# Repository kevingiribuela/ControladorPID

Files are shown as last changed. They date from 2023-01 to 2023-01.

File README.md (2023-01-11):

# ControladorPID
 Controlador PID desarrollado en 4to año de la carrera

## Descripción
Este diseño se realizó basandose en los principios del control robusto. El objetivo es realizar el control automático de una planta conocida pero cuyos parámetros pueden variar en función de agentes externos como lo son la temperatura, la humedad, etc. Es por eso que el controlador debe no solo controlar a la planta nominal sino que también a la familia de plantas involucradas en el modelo. 

La planta se trata de una serie de filtros pasabajos en cascada implementados con amplificadores operacionales, resistencias y capacitores. Los archivos correspondientes al diseño de la placa se encuentran en la presente documentación.

La placa es capaz de realizar una identificación de la planta a partir de un escalón a su entrada y enviar los datos en tiempo real a MATLAB para su procesamiento de datos y posterior modelado a partir de un modelo de primer orden. 



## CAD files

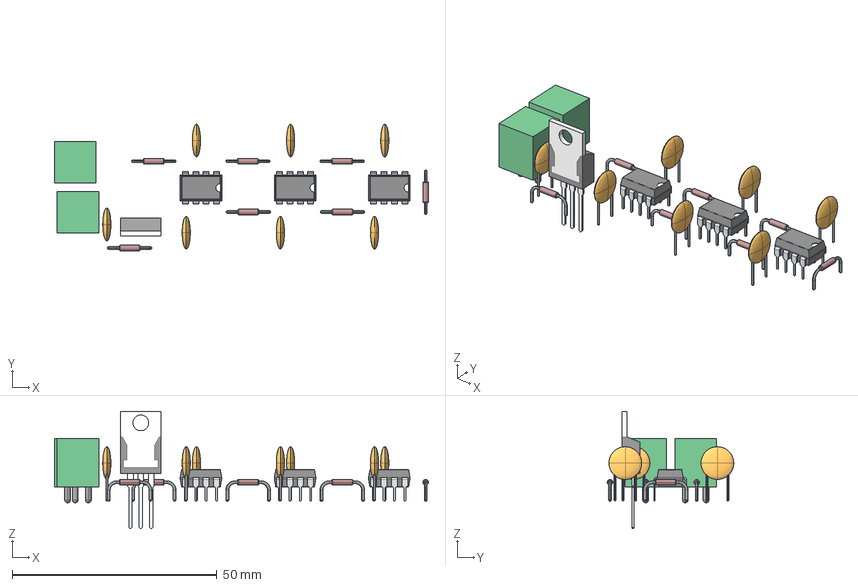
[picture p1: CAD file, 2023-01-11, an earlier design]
PCB/PCB_V1/Placa_control.STEP
91.4 x 30.9 x 28.6 mm
Pin_1 x 16
Pin_2 x 16

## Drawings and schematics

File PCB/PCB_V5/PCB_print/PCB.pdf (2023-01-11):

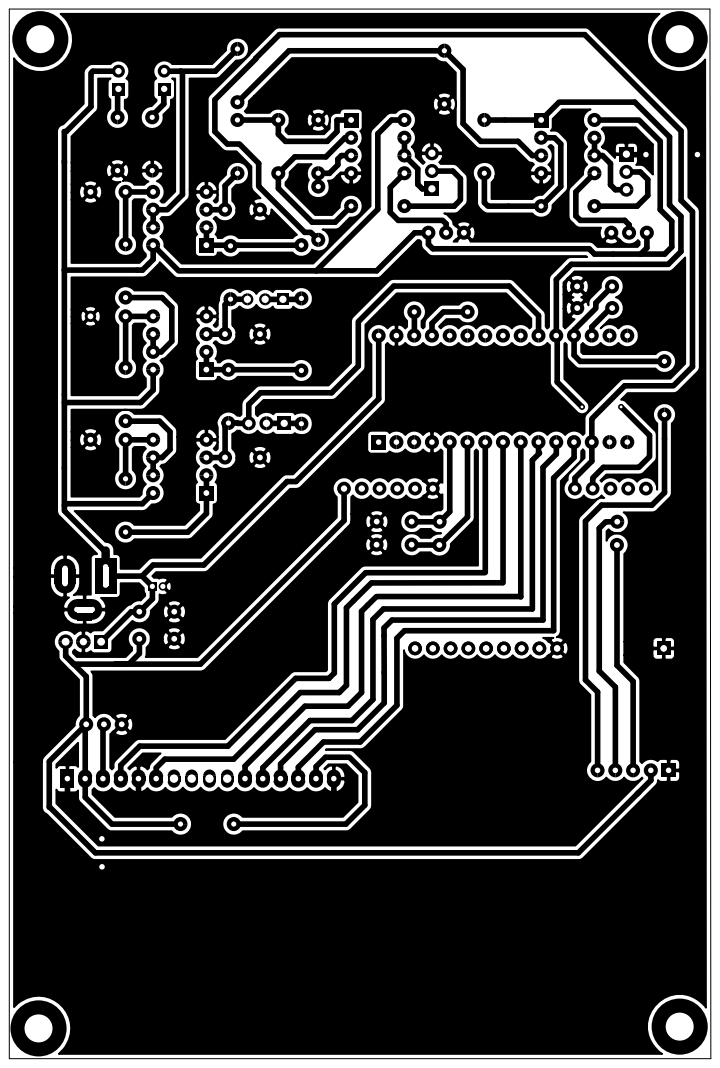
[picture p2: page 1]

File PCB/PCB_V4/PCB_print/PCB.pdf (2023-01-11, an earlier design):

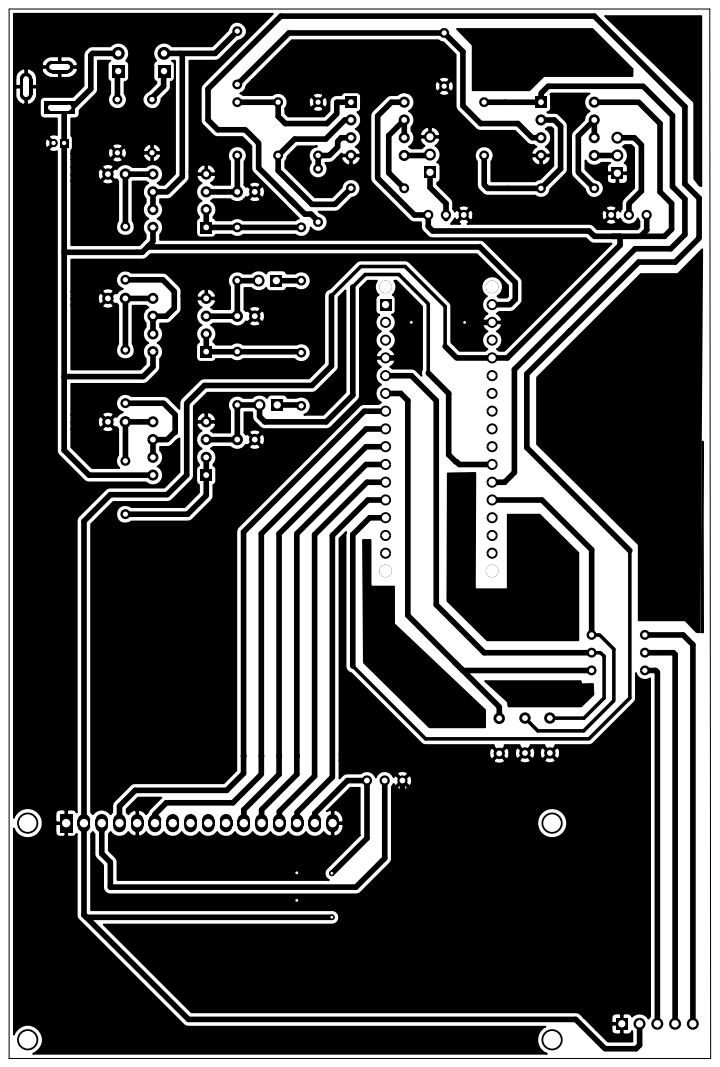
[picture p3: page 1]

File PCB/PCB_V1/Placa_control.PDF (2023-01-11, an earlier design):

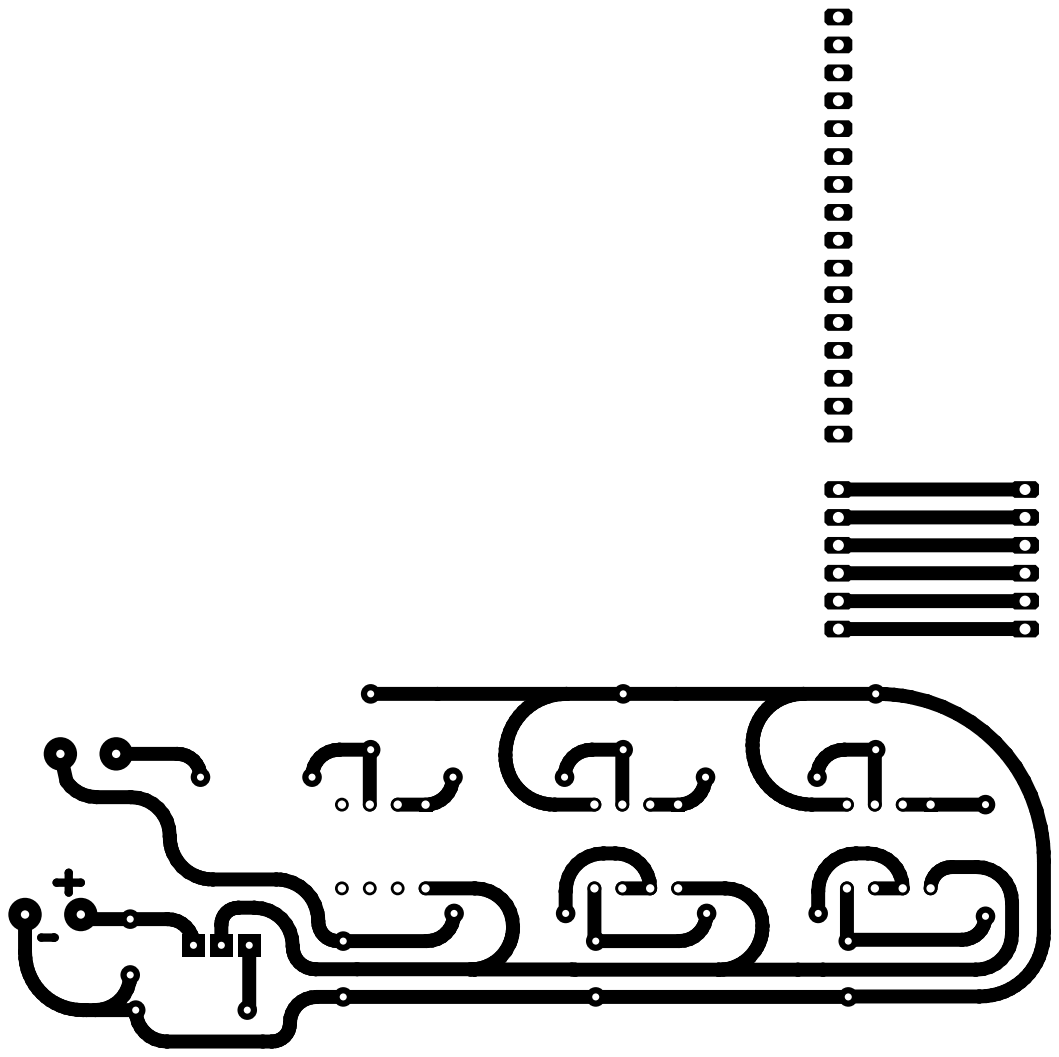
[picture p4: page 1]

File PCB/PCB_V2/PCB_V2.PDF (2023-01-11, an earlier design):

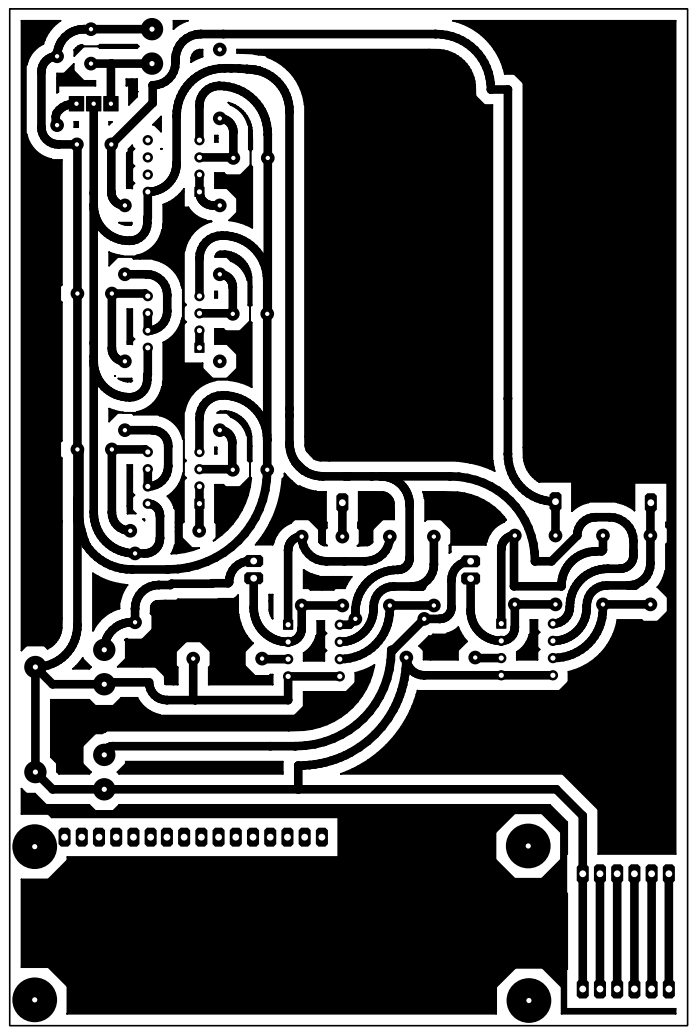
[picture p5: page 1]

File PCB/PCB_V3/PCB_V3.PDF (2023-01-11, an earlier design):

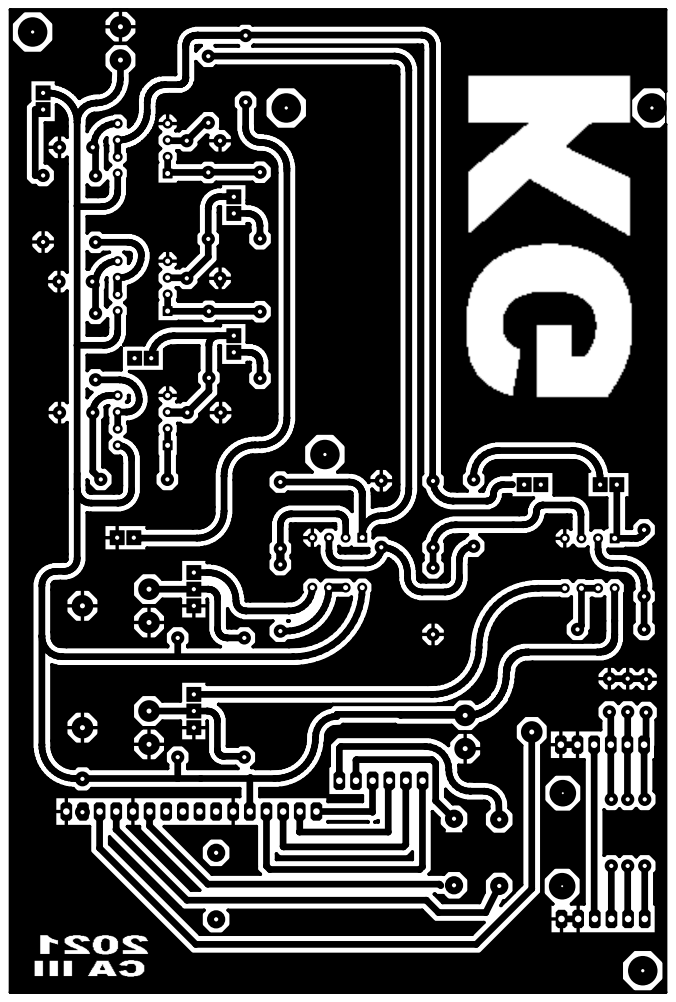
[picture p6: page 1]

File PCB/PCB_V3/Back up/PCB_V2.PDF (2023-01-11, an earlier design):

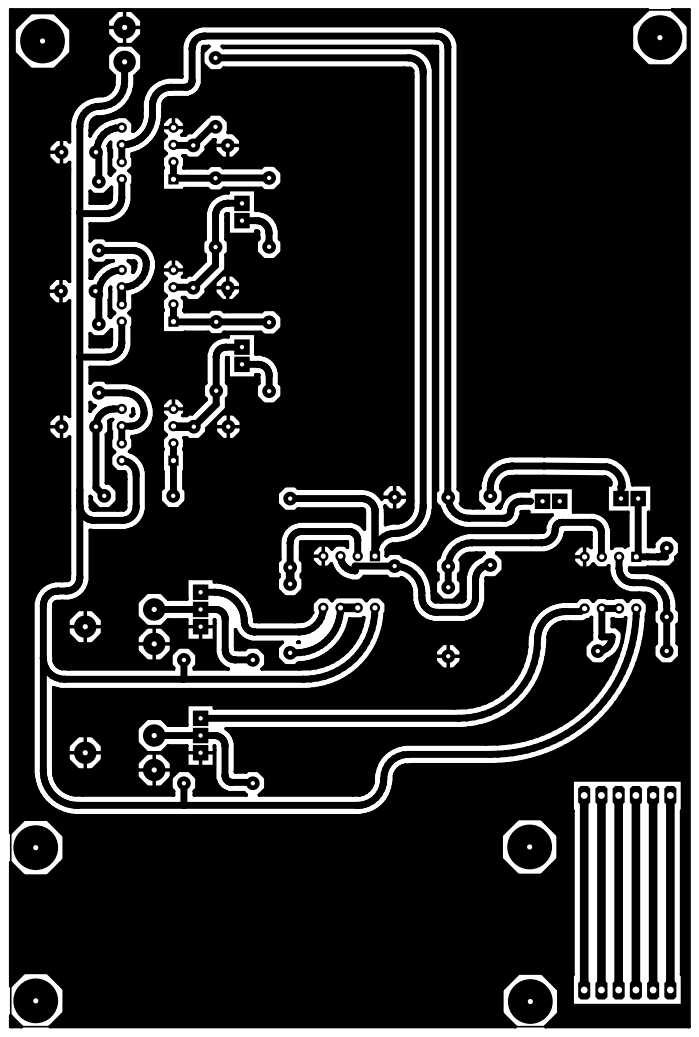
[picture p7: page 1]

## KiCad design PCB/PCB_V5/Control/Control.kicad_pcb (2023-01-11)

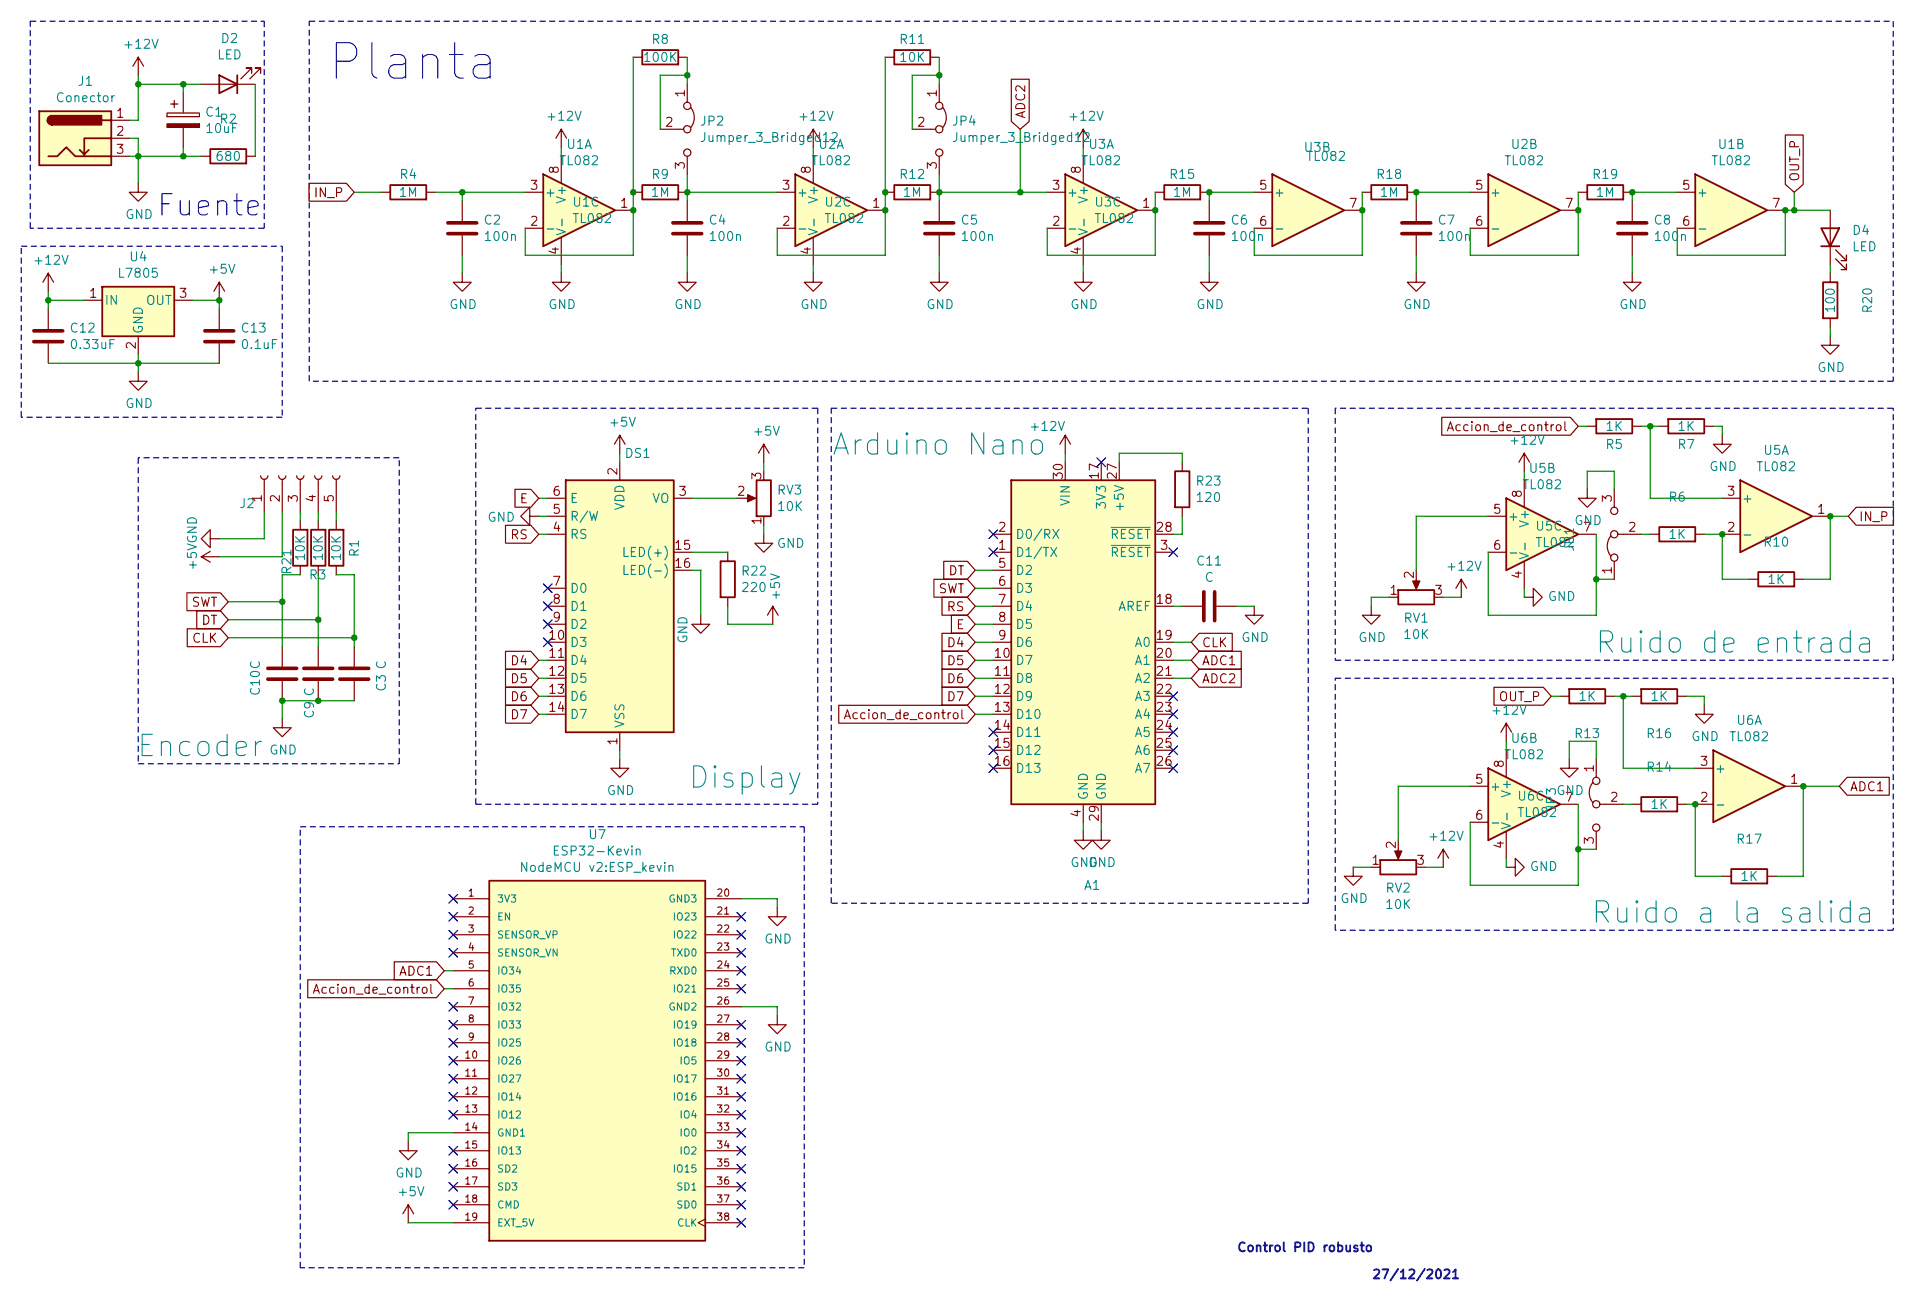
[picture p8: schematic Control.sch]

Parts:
A1: Arduino Nano; Arduino_Nano_WithMountingHoles
C1: 10uF; CP_Radial_D4.0mm_P1.50mm
C2, C4, C5, C6, C7, C8: 100n; C_Disc_D4.3mm_W1.9mm_P5.00mm
C3, C9, C10, C11: C; C_Disc_D4.3mm_W1.9mm_P5.00mm
C12: 0.33uF; C_Disc_D4.3mm_W1.9mm_P5.00mm
C13: 0.1uF; C_Disc_D4.3mm_W1.9mm_P5.00mm
D2, D4: LED; LED_D5.0mm_Clear
DS1: Display; WC1602A
J1: Conector; BarrelJack_Wuerth_6941xx301002
J2: Encoder; PinHeader_1x05_P2.54mm_Vertical
JP1: Ruido de entrada; PinHeader_1x03_P2.54mm_Vertical
JP2, JP4: Jumper_3_Bridged12; PinHeader_1x03_P2.54mm_Vertical
JP3: Ruido a la salida; PinHeader_1x03_P2.54mm_Vertical
R1, R11: 10K; R_Axial_DIN0204_L3.6mm_D1.6mm_P7.62mm_Horizontal
R2: 680; R_Axial_DIN0204_L3.6mm_D1.6mm_P7.62mm_Horizontal
R3, R21: 10K; R_Axial_DIN0309_L9.0mm_D3.2mm_P25.40mm_Horizontal
R4, R9, R12, R15, R18, R19: 1M; R_Axial_DIN0204_L3.6mm_D1.6mm_P7.62mm_Horizontal
R5, R6, R7, R10, R13, R14, R16, R17: 1K; R_Axial_DIN0204_L3.6mm_D1.6mm_P7.62mm_Horizontal
R8: 100K; R_Axial_DIN0204_L3.6mm_D1.6mm_P7.62mm_Horizontal
R20: 100; R_Axial_DIN0204_L3.6mm_D1.6mm_P7.62mm_Horizontal
R22: 220; R_Axial_DIN0204_L3.6mm_D1.6mm_P7.62mm_Horizontal
R23: 120; R_Axial_DIN0204_L3.6mm_D1.6mm_P7.62mm_Horizontal
RV1, RV2, RV3: 10K; Potentiometer_Bourns_3266Y_Vertical
U1, U2, U3: TL082; DIP-8_W7.62mm_Socket
U4: L7805; TO-220-3_Vertical
U5, U6: TL082; DIP-8_W7.62mm
U7: ESP32-Kevin; ESP_kevin; PARTREV 4

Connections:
+5V: C13.1, DS1.2 (VDD), J2.2, R22.2, RV3.3, U4.3 (OUT), U7.19 (EXT_5V)
+12V: A1.30 (VIN), C1.1, C12.1, D2.2 (A), J1.1, RV1.3, RV2.3, U1.8 (V+), U2.8 (V+), U3.8 (V+), U4.1 (IN), U5.8 (V+), U6.8 (V+)
ADC1: A1.20 (A1), R17.2, U6.1, U7.5 (IO34)
ADC2: A1.21 (A2), C5.1, JP4.3 (B), R12.2, U3.3 (+)
Accion_de_control: A1.13 (D10), R5.2, U7.6 (IO35)
CLK: A1.19 (A0), C3.2, R1.1
D4: A1.9 (D6), DS1.11 (D4)
D5: A1.10 (D7), DS1.12 (D5)
D6: A1.11 (D8), DS1.13 (D6)
D7: A1.12 (D9), DS1.14 (D7)
DT: A1.5 (D2), C9.1, R3.1
E: A1.8 (D5), DS1.6 (E)
GND: A1.4 (GND), A1.29 (GND), C1.2, C2.2, C3.1, C4.2, C5.2, C6.2, C7.2, C8.2, C9.2, C10.2, C11.1, C12.2, C13.2, DS1.1 (VSS), DS1.5 (R/W), DS1.16 (LED(-)), J1.2, J1.3, J2.1, JP1.3 (B), JP3.1 (A), R2.1, R7.1, R16.1, R20.2, RV1.1, RV2.1, RV3.1, U1.4 (V-), U2.4 (V-), U3.4 (V-), U4.2 (GND), U5.4 (V-), U6.4 (V-), U7.14 (GND1), U7.20 (GND3), U7.26 (GND2)
IN_P: R4.1, R10.2, U5.1
unnamed: A1.18 (AREF), C11.2
unnamed: A1.27 (+5V), R23.1
unnamed: A1.28 (~RESET), R23.2
unnamed: C2.1, R4.2, U1.3 (+)
unnamed: C4.1, JP2.3 (B), R9.2, U2.3 (+)
unnamed: C6.1, R15.2, U3.5 (+)
unnamed: C7.1, R18.2, U2.5 (+)
unnamed: C8.1, R19.2, U1.5 (+)
unnamed: D2.1 (K), R2.2
unnamed: D4.1 (K), R20.1
unnamed: DS1.3 (VO), RV3.2
unnamed: DS1.15 (LED(+)), R22.1
unnamed: J2.3, R21.2
unnamed: J2.4, R3.2
unnamed: J2.5, R1.2
unnamed: JP1.1 (A), U5.6 (-), U5.7
unnamed: JP1.2 (C), R6.1
unnamed: JP2.1 (A), JP2.2 (C), R8.2
unnamed: JP3.2 (C), R14.1
unnamed: JP3.3 (B), U6.6 (-), U6.7
unnamed: JP4.1 (A), JP4.2 (C), R11.2
unnamed: R5.1, R7.2, U5.3 (+)
unnamed: R8.1, R9.1, U1.1, U1.2 (-)
unnamed: R6.2, R10.1, U5.2 (-)
unnamed: R11.1, R12.1, U2.1, U2.2 (-)
unnamed: R13.1, R16.2, U6.3 (+)
unnamed: R14.2, R17.1, U6.2 (-)
unnamed: R15.1, U3.1, U3.2 (-)
unnamed: R18.1, U3.6 (-), U3.7
unnamed: R19.1, U2.6 (-), U2.7
unnamed: RV1.2, U5.5 (+)
unnamed: RV2.2, U6.5 (+)
OUT_P: D4.2 (A), R13.2, U1.6 (-), U1.7
RS: A1.7 (D4), DS1.4 (RS)
SWT: A1.6 (D3), C10.1, R21.1

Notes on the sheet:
27/12/2021
Control PID robusto
Planta
Fuente

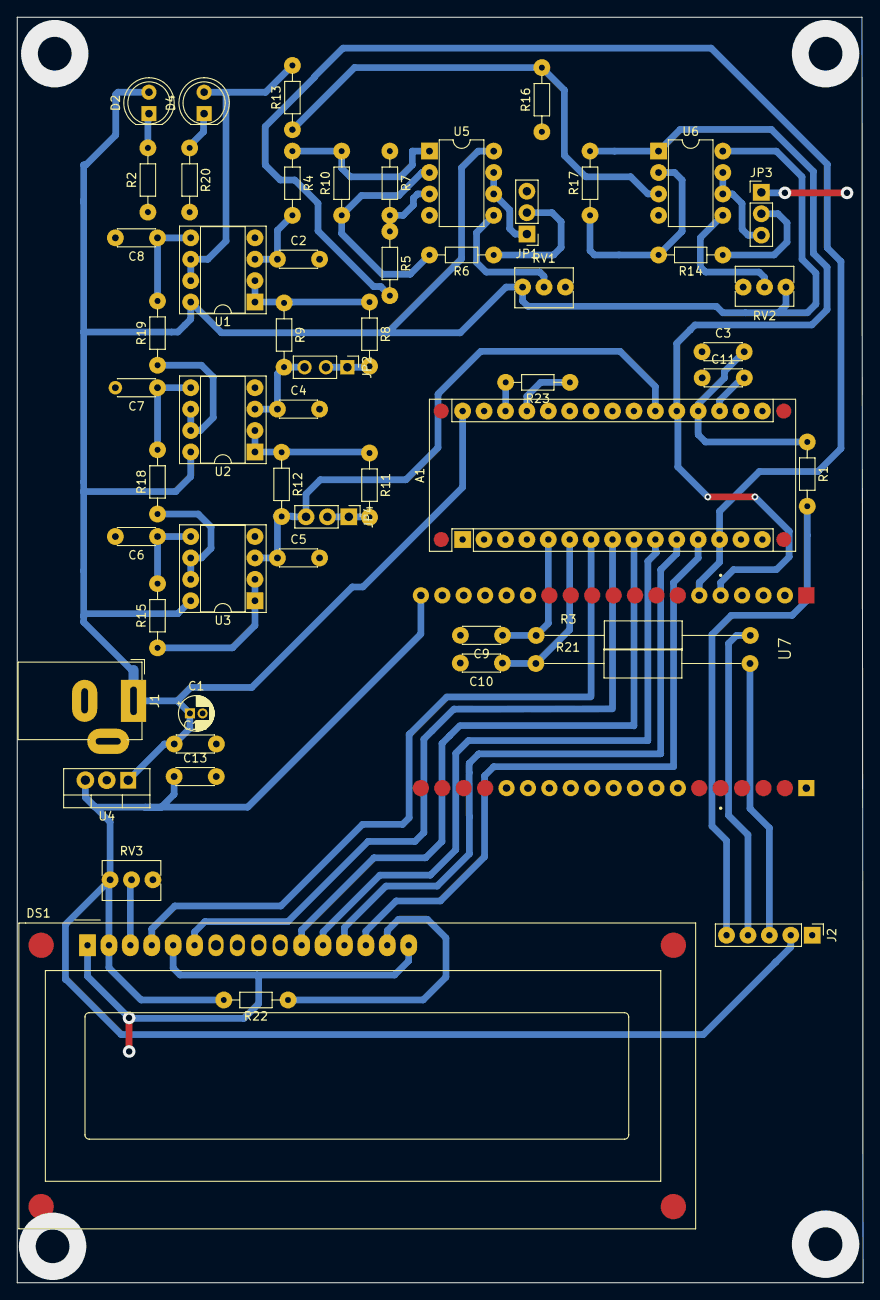
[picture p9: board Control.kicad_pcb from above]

Board: 2 copper layers, 100.3 x 150.1 mm, 56 parts (0 on the bottom side), 49 nets.

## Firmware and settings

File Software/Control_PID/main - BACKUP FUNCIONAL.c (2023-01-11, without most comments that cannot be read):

/*
* Control_PID.c
*
* Created: 26/12/2021 17:30:35
* Author : Kevin Giribuela
*/

#include <avr/io.h>
#include <avr/interrupt.h>
#include <math.h>
#include <encoder.h>
#include <LCD_AVR.h>
#include <USART.h>
#include <PWM.h>
#include <ADC.h>

#define Ts	47				// OCR1B register for 325.52Hz interrupt

#define ADQ	9				// Adquisition mode
#define PID 10				// PID mode

#define PID_IMC 11			// Controlador IMC
#define PID_canPC 12		// Controlador cancelacion polo-cero

#define toggle(x,y) x^=(1<<y)

/************************************************VARIABLES************************************************/
/********************************************************************************************************/
// Interrupts flags
volatile unsigned char button=0, turn=0, conversion=0, matlab=0, actualizar=0;
volatile uint16_t contador=0;

// Global vars
unsigned char routine=0, cursor=0, enter=0, modo=0, mode_selection=0, controller_selection=0;
unsigned char intro=0, select=0, ok=0, curA=50, curb=50, curc=50, curRef=50;

// ADC values
unsigned int ADC_H=0, ADC_L=0, muestras=0;

// PID values
float L=0.325, T=0.324, Kp=1, T0=0, Tf=0;		// Modelo de la planta
float Tds=0, Tis=0, Kxs=0;
float Tdp=0, Tip=0, Kxp=0;
float error_anterior=0, error_actual=0, P=0, I=0, D=0, q=1;						// Valores del PID paralelo
float x_pid[2]={0,0}, y_pid[2]={0,0}, a_pid[2]={0,0}, b_pid[2]={0,0};			// Coeficientes del filtro pasa bajos y del PID
float x_ref[3]={2.5,0,0}, y_ref[3]={0,0,0}, b_ref[3]={0,0,0}, a_ref[3]={0,0,0};	// Coeficientes del filtro a la ref y de la ref
float T_samp=0.003074;
float A=0.5, b=0.5, c=0.5;


/************************************************FUNCTIONS***********************************************/
/********************************************************************************************************/
// Timer0 initialization
void TIMER0_init(void);
void TIMER0_off(void);

// Main functions
void mode_off(void);
void dispatch(void);

// PID functions
void PID_parametters(void);
void PID_off(void);
void print_value(unsigned char, unsigned char);
void update_value(unsigned char, unsigned char, unsigned char);
float accion_de_control(void);
void step_on(void);
void step_off(void);


/********************************************************************************************************/
/********************************************************************************************************/

/*******************************************INTERRUPT HANDLERS*******************************************/
/********************************************************************************************************/
// Handler UART RX ready
ISR(USART_RX_vect){
	matlab=USART_read();
}

// Clear OCF0A flag
ISR(TIMER0_COMPA_vect){;}

// ADC complete
ISR(ADC_vect){
	conversion=1;
	contador++;
	if(contador==500){actualizar=1; contador=0;}
}

// Encoder button
ISR(INT1_vect){
	button=1;
}

// Encoder potentiometer
ISR(INT0_vect){
	turn=1;
}
/********************************************************************************************************/
/********************************************************************************************************/

/**********************************************MAIN PROGRAM**********************************************/
/********************************************************************************************************/
int main(void)
{	
	// Acción de control
	DDRB|= (1<<DDB2);
	
	// LED built-on
	DDRB|=(1<<DDB5);
	
	/****************************************************************/
	// LCD Initialization
	LCD_Init();
	
	// UART Initialization
	USART_Init();
	
	// Encoder Initialization
	encoder_init();
	
	// Timer0 Initialization
	TIMER0_init();

	 LCD_write_string_xy("   Bienvenido   ",1,1);
	_delay_ms(1000);
	LCD_clear();
	
	LCD_write_string_xy("Control III &",1,1);
	LCD_write_string_xy("Arquitectura",2,1);
	_delay_ms(1000);
	
	
	// Global interrupts enable
	sei();
	
	while(1){
		if(mode_selection!=1){

			LCD_clear();
			LCD_write_string_xy("Seleccione modo:",1,0);
			LCD_write_string_xy("PID",2,1);
			LCD_write_string_xy("ADQ",2,13);
			LCD_gotoxy(2,0);
			LCD_write('>');
			cursor=0;
		}
		while(mode_selection!=1){
			// Detecto si se gira el potenciometro del encoder
			if(turn){
				if((rotation())=='+'){
					if(cursor==1){cursor=0;}	// If OVF cursor...
					else{cursor++;}
				}
				else if((rotation())=='-'){
					if(cursor==0){cursor=1;}	// If UDF cursor...
					else{cursor--;}
				}
				// Una vez hecho el giro del potenciometro, muevo el "cursor" del display al modo seleccionado
				if(cursor==0){LCD_write_string_xy(">PID         ADQ",2,0);}
				else{LCD_write_string_xy(" PID        >ADQ",2,0);}
				turn=0;
			}
			// Detecto si se presiona el pulsador del encoder
			if(button&&!(cursor)){modo=PID; button=0; mode_selection=1;}
			else if(button&&cursor){modo=ADQ; button=0; mode_selection=1;}
		}

		if(modo==ADQ){
			OCR1B=0;
			ADC_init(ADQ);
			PWM_init();
			USART_enable();
			
			LCD_clear();
			LCD_write_string_xy("Esperando a",1,0);
			LCD_write_string_xy("MATLAB... >Atras",2,0);


			matlab=0; // Clear flag
			while(matlab==0){
				if(button){button=0; routine=0; matlab=2; mode_selection=0; modo=0;}
			}
			// Si se recibió la señal deseada, muestreo
			if(matlab==1){
				LCD_clear();
				LCD_write_string_xy("Muestreando...",1,0);
				routine=1;
				matlab=0;
				step_on();
			}
		}

		else if(modo==PID){
			LCD_clear();
			LCD_write_string_xy("Controlador:",1,0);
			LCD_write_string_xy("Canc. polo/cero",2,1);
			LCD_gotoxy(2,0);
			LCD_write('>');
			cursor=0;
			controller_selection=0;
			enter=0;
			// Selecciono el controlador que se desea implementar
			while(enter!=1){
				// Detecto si se gira el potenciometro del encoder
				if(turn){
					if((rotation())=='+'){
						if(cursor==2){cursor=0;}	// If OVF cursor...
						else{cursor++;}
					}
					else if((rotation())=='-'){
						if(cursor==0){cursor=2;}	// If UDF cursor...
						else{cursor--;}
					}
					// Una vez hecho el giro del potenciometro, muevo el "cursor" del display al controlador seleccionado
					switch(cursor){
						case 0:
						{
							LCD_write_string_xy("Canc. polo/cero ",2,1);
							LCD_gotoxy(2,0);
							LCD_write('>');
							break;
						}
						case 1:
						{
							LCD_write_string_xy("Enfoque IMC     ",2,1);
							LCD_gotoxy(2,0);
							LCD_write('>');
							break;
						}
						case 2:
						{
							LCD_write_string_xy("Atras           ",2,1);
							LCD_gotoxy(2,0);
							LCD_write('>');
							break;
						}
						default:
						break;
					}
					turn=0;
				}
				// Detecto si se presiona el pulsador del encoder
				if(button&&(cursor==0)){controller_selection=PID_canPC; button=0; enter=1;}
				else if(button&&(cursor==1)){controller_selection=PID_IMC; button=0; enter=1;}
				else if(button&&(cursor==2)){controller_selection=0; button=0; enter=1; routine=0; mode_selection=0; modo=0;}
				else{asm("NOP");}
			}

			//toggle(PORTB,PORTB5);
			switch(controller_selection){
				case 0:
					break;
				case PID_canPC:
				{
					// Selección de parámetros A (alpha), b y c
					PID_parametters();
					

					T0=(sqrt(A*A+A)+A)*L/2;
					Kxs=(2*T)/((L+4*T0)*Kp);
					
					break;
				}
				case PID_IMC:
				{
					// Seleccián de parámetros A (alpha), b y c
					PID_parametters();

					// Cálculo de parámetros del controlador IMC
					T0=L*A/(1-A);
					Kxs=T/(L+T0)/Kp;

					break;
				}
			}

			// En caso de haber seleccionado "OK", se inicializa el ADC y el TIMER1 (PWM) para generar la acción de control y se calculan los coeficientes
			if(routine){
				ADC_init(PID);
				PWM_init();
				cursor=0;
				
				// Calculo de parámetros del PID serie
				Tds=L/2;
				Tis=T;

				// Cálculo de parámetros de PID paralelo
				Tip=Tis+Tds;
				Tdp=Tis*Tds/Tip;
				Kxp=Kxs*Tip/Tis;
				Tf=L*A/2;

				// Coeficientes del filtro PID
				a_pid[0]=T_samp+2*Tf;
				a_pid[1]=T_samp-2*Tf;

				b_pid[0]=T_samp;
				b_pid[1]=T_samp;

				// Coeficientes del filtro a la referencia
				b_ref[0]=T_samp*T_samp+b*Tip*2*T_samp+c*Tip*Tdp*4;
				b_ref[1]=2*T_samp*T_samp-8*c*Tip*Tdp;
				b_ref[2]=T_samp*T_samp-b*Tip*2*T_samp+c*Tip*Tdp*4;
							
				a_ref[0]=T_samp*T_samp+Tip*2*T_samp+Tip*Tdp*4;
				a_ref[1]=2*T_samp*T_samp-8*Tip*Tdp;
				a_ref[2]=T_samp*T_samp-Tip*2*T_samp+Tip*Tdp*4;

				// Inicialización de valores en display
				LCD_clear();
				LCD_write_string_xy("Vout=     A=    ",1,0);
				LCD_write_string_xy("Vref=    ",2,0);
				update_value('R',curRef,0);
				update_value('O',0,0);
				update_value('A',curA,0);
			}
		}
		else{asm("NOP");}
		// Bucle de accion
		while (routine){
			dispatch();
		}
	}
}
/********************************************************************************************************/
/********************************************************************************************************/

/******************************************FUNCTION DECLARATION******************************************/
/********************************************************************************************************/
void dispatch (void ){
	

	if(conversion){
		if(modo==PID){
			// Actualizo el ciclo de trabajo del PWM
			PWM_duty(accion_de_control());
			if(actualizar==1){
				update_value('R',curRef,0);
				update_value('O',0,0);
				update_value('A',curA,0);	
				actualizar=0;
			}
		}
		else if(modo==ADQ){

			USART_write(ADC&0xFF);
			USART_write(ADC>>8);

			if(matlab==1){
				LCD_clear();
				LCD_write_string_xy("Fin de muestreo.",1,0);
				_delay_ms(3000);
				routine=0;
				mode_selection=0;
				modo=0;
				USART_disable();
				ADC_disable();
				step_off();
			}
		}
		conversion=0;	// Clear flag
	}
	// Si se presiona el boton del encoder y me encuentro en el modo PID, detengo el controlador y entro al menú de parámetros
	if(button&&(modo==PID)){
		button=0;
		OCR1B=0;
		P=0; I=0; D=0;

		LCD_clear();
		LCD_write_string_xy(">Vref=      OK",1,0);
		LCD_write_string_xy(" A=      Atras",2,0);
		update_value('R',curRef,1);
		update_value('A',curA,1);

		cursor=0;
		enter=0;
		while(enter!=1){
			if(turn){
				if((rotation())=='+'){
					if(cursor==3){cursor=0;}	// If OVF cursor...
					else{cursor++;}
				}
				else if((rotation())=='-'){
					if(cursor==0){cursor=3;}	// If UDF cursor...
					else{cursor--;}
				}
				switch(cursor){
					case 0:
					{
						LCD_gotoxy(1,0);
						LCD_write('>');

						LCD_gotoxy(1,11);
						LCD_write(' ');
						LCD_gotoxy(2,0);
						LCD_write(' ');
						LCD_gotoxy(2,8);
						LCD_write(' ');
						break;
					}
					case 1:
					{
						LCD_gotoxy(1,11);
						LCD_write('>');

						LCD_gotoxy(1,0);
						LCD_write(' ');
						LCD_gotoxy(2,0);
						LCD_write(' ');
						LCD_gotoxy(2,8);
						LCD_write(' ');
						break;
					}

					case 2:
					{
						LCD_gotoxy(2,0);
						LCD_write('>');

						LCD_gotoxy(1,11);
						LCD_write(' ');
						LCD_gotoxy(1,0);
						LCD_write(' ');
						LCD_gotoxy(2,8);
						LCD_write(' ');
						break;
					}

					case 3:
					{
						LCD_gotoxy(2,8);
						LCD_write('>');

						LCD_gotoxy(1,11);
						LCD_write(' ');
						LCD_gotoxy(1,0);
						LCD_write(' ');
						LCD_gotoxy(2,0);
						LCD_write(' ');
						break;
					}

					default:
						break;
					}
				turn=0;
			}
			if(button&&cursor==0){	// Rutina si se presiona la opción Vref
				button=0;
				LCD_gotoxy(1,7);
				LCD_blinkON();
				intro=0;
				while(intro!=1){
					if(turn){
						if(rotation()=='+'){
							if(curRef==100){curRef=0;}	// If OVF cursor...
							else{curRef++;}
						}
						else if(rotation()=='-'){
							if(curRef==0){curRef=100;}	// If UDF cursor...
							else{curRef--;}
						}
						update_value('R',curRef,1);
						x_ref[0]=(float)curRef*5/100;
						turn=0;
					}
					if(button){button=0; intro=1; LCD_blinkOFF();}
				}
			}
			if(button&&cursor==1){	// Rutina si se presiona la opción OK
				button=0;
				enter=1;

				LCD_clear();
				LCD_write_string_xy("Vout=     A=    ",1,0);
				LCD_write_string_xy("Vref=",2,0);
			}
			if(button&&cursor==2){	// Rutina si se presiona la opción A
				button=0;
				LCD_gotoxy(2,4);
				LCD_blinkON();
				intro=0;
				while(intro!=1){
					if(turn){
						if(rotation()=='+'){
							if(curA==100){curA=0;}	// If OVF cursor...
							else{curA++;}
						}
						else if(rotation()=='-'){
							if(curA==0){curA=100;}	// If UDF cursor...
							else{curA--;}
						}
						update_value('A',curA,1);
						A=(float)curA/100;
						turn=0;
					}
					if(button){button=0; intro=1; LCD_blinkOFF();}
				}
			}
			if(button&&cursor==3){	// Rutina si se presiona la opción Atras
				button=0;
				enter=1;
				routine=0;

				LCD_clear();

				// Reset PID parameters
				x_ref[0]=2.5;
				curA=50;
				curb=50;
			}
		}
	}
}

void TIMER0_init(void){
	// Timer 0 mode: CTC
	TCCR0A|=(0<<WGM00);
	TCCR0A|=(1<<WGM01);
	TCCR0B|=(0<<WGM02);
	

	OCR0A=Ts;
	
	// Interrupt on compare: ON
	TIMSK0|=(1<<OCIE0A);
	
	// Prescaler Timer0: 1024.
	TCCR0B|=(1<<CS02)|(0<<CS01)|(1<<CS00);
}
void mode_off(void){
	USART_disable();
	ADC_disable();
}

/******PID functions*******/
void PID_parametters(void ){
	//select=0--> Vref	 select=1--> A		select=2--> b		select=3--> c		select=4--> Atras		select=5-->OK
	LCD_clear();
	LCD_write_string_xy("Parametros: ",1,0);
	print_value('R',curRef);

	//Asigno valores por defecto
	x_ref[0]=(float)curRef*5/100;
	A=(float)curA/100;
	b=(float)curb/100;
	c=(float)curc/100;

	ok=0;
	select=0;
	while(ok!=1){
		if(turn){					// Detecto si se giro el encoder
			if(rotation()=='+'){
				if(select==5){select=0;}	// If OVF cursor...
				else{select++;}
			}
			else if(rotation()=='-'){
				if(select==0){select=5;}	// If UDF cursor...
				else{select--;}
			}
			LCD_write_string_xy("                ",2,0);
			switch(select){
				case 0:
					print_value('R',curRef);
					x_ref[0]=(float)curRef*5/100;
					break;
				case 1:
					print_value('A',curA);
					A=(float)curA/100;
					break;
				case 2:
					print_value('b',curb);
					b=(float)curb/100;
					break;
				case 3:
					print_value('c',curc);
					c=(float)curc/100;
					break;
				case 4:
					LCD_write_string_xy(">Atras",2,0);
					break;
				case 5:
					LCD_write_string_xy(">OK",2,0);
					break;
				default:
					break;
			}
			turn=0;					//  Clear flag
		}
		
		if(button&&select==0){
			button=0;
			LCD_blinkON();
			intro=0;
			while(intro!=1){
				if(turn){
					if(rotation()=='+'){
						if(curRef==100){curRef=0;}	// If OVF cursor...
						else{curRef++;}
					}
					else if(rotation()=='-'){
						if(curRef==0){curRef=100;}	// If UDF cursor...
						else{curRef--;}
					}
					print_value('R',curRef);
					x_ref[0]=(float)curRef*5/100;
					turn=0;
				}
				if(button){button=0; intro=1; LCD_blinkOFF();}
			}
		}
		if(button&&select==1){
			button=0;
			LCD_blinkON();
			intro=0;
			while(intro!=1){
				if(turn){
					if(rotation()=='+'){
						if(curA==100){curA=0;}	// If OVF cursor...
						else{curA++;}
					}
					else if(rotation()=='-'){
						if(curA==0){curA=100;}	// If UDF cursor...
						else{curA--;}
					}
					print_value('A',curA);
					A=(float)curA/100;
					turn=0;
				}
				if(button){button=0; intro=1; LCD_blinkOFF();}
			}
		}
		if(button&&select==2){
			button=0;
			LCD_blinkON();
			intro=0;
			while(intro!=1){
				if(turn){
					if((rotation())=='+'){
						if(curb==100){curb=0;}	// If OVF cur...
						else{curb++;}
					}
					else if((rotation())=='-'){
						if(curb==0){curb=100;}	// If UDF cur...
						else{curb--;}
					}
					print_value('b',curb);
					b=(float)curb/100;
					turn=0;
				}
				if(button){button=0; intro=1; LCD_blinkOFF();}
			}
		}
		if(button&&select==3){
			button=0;
			LCD_blinkON();
			intro=0;
			while(intro!=1){
				if(turn){
					if((rotation())=='+'){
						if(curc==100){curc=0;}	// If OVF cur...
						else{curc++;}
					}
					else if((rotation())=='-'){
						if(curc==0){curc=100;}	// If UDF cur...
						else{curc--;}
					}
					print_value('c',curc);
					c=(float)curc/100;
					turn=0;
				}
				if(button){button=0; intro=1; LCD_blinkOFF();}
			}
		}
		if(button&&select==4){
			button=0;
			ok=1;
			routine=0;
		}
		if(button&&select==5){
			button=0;
			ok=1;
			routine=1;
		}
	}
	return;
}
void print_value(unsigned char value_print, unsigned char cursor){
	int cursor_aux=cursor;
	unsigned char aux, i;
	if(value_print=='R'){
		cursor_aux=5*cursor_aux;
	}
	LCD_gotoxy(2,0);
	LCD_write('>');
	LCD_gotoxy(2,1);
	LCD_write(value_print);
	LCD_gotoxy(2,2);
	LCD_write('=');
	for(i=0;i<3;i++){
		aux=cursor_aux%10;
		cursor_aux=cursor_aux/10;
		if(i==2){
			LCD_gotoxy(2,4);
			LCD_write(',');
			LCD_gotoxy(2,3);
		}
		else{
			LCD_gotoxy(2,6-i);
		}
		LCD_write(48+aux);
		if(i==2){
			LCD_gotoxy(2,7);
		}
	}
	return;
}
void update_value(unsigned char value_print, unsigned char cursor, unsigned char mod){
	uint16_t cursor_aux=cursor;
	unsigned char aux, i, fila, columna;
	if((value_print=='R')&&(mod==0)){
		cursor_aux=5*cursor_aux;
		fila=2;
		columna=8;
	}
	else if((value_print=='R')&&(mod=1)){
		cursor_aux=5*cursor_aux;
		fila=1;
		columna=9;
	}
	else if((value_print=='A')&&(mod==0)){
		fila=1;
		columna=15;
	}
	else if((value_print=='A')&&(mod==1)){
		fila=2;
		columna=6;
	}
	else{
		fila=1;
		columna=8;
		cursor_aux=ADC;
		cursor_aux=(int)(((float)cursor_aux*5/1024)*100);
		
	}
	for(i=0;i<3;i++){
		aux=cursor_aux%10;
		cursor_aux=cursor_aux/10;
		if(i==2){
			LCD_gotoxy(fila,columna-2);
			LCD_write(',');
			LCD_gotoxy(fila,columna-3);
		}
		else{
			LCD_gotoxy(fila,columna-i);
		}
		LCD_write(48+aux);
	}
	return;
}
float accion_de_control(void){
	// Filtro a la referencia
	y_ref[0]=1/a_ref[0]*(b_ref[0]*x_ref[0]+b_ref[1]*x_ref[1]+b_ref[2]*x_ref[2]-a_ref[1]*y_ref[1]-a_ref[2]*y_ref[2]);

	// Actualizo valores del filtro a la referencia
	y_ref[2]=y_ref[1];
	y_ref[1]=y_ref[0];
	
	x_ref[2]=x_ref[1];
	x_ref[1]=x_ref[0];
	
	// Calculo del error y parámetros del PID paralelo
	error_actual=y_ref[0]-((float)ADC*5/1024);
	P=error_actual*Kxp;								// Proporcional
	I+=T_samp*error_actual*q/Tip*Kxp;				// Integral
	D=(error_actual-error_anterior)/T_samp*Tdp*Kxp;	// Derivativo		
			
	x_pid[0]=P+I+D;
	error_anterior=error_actual;					// Actualizo el error
	
// Filtro para el PID paralelo
	y_pid[0]=1/a_pid[0]*(b_pid[0]*x_pid[0]+b_pid[1]*x_pid[1]-a_pid[1]*y_pid[1]);	
	
// Actualizo valores del PID
	y_pid[1]=y_pid[0];
	x_pid[1]=x_pid[0];


// Retorno de valores
	if(y_pid[0]>5){			// Saturacion
		y_pid[0]=5;
		q=0;
	}
	else if(y_pid[0]<0){	// Saturacion
		y_pid[0]=0;
		q=0;
	}
	else{
		q=1;
	}
	
	return y_pid[0];
	
}
void step_on(void){
	OCR1B=1023;
}
void step_off(void){
	OCR1B=0;
}
/**************************/

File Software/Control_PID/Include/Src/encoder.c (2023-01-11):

	#include <avr/io.h>
	#include <encoder.h>
	
	void encoder_init(void){
		/* PINOUT ENCODER CONFIGURATION */
		// PORTC0 as INPUT - CLK
		DDRC &=~(1<<DDC0);
		
		// PORTD2 as INPUT - DT
		DDRD &=~(1<<DDD2);
	
		// PORTD3 as Pull-Up INPUT - SWT
		DDRD &=~(1<<DDD3);
		PORTD|= (1<<PORTD3);
		/********************************/
		
		
		/* INTERRUPT ENCODER CONFIGURATION */ 
		// Any logical change on INT0 generates an interrupt request.
		EICRA&=~(1<<ISC01);
		EICRA|= (1<<ISC00);
		
		// The falling edge of INT1 generates an interrupt request.
		EICRA|= (1<<ISC11);
		EICRA&=~(1<<ISC10);
		
		// Interrupt INT1/0 enable
		EIMSK|= (1<<INT1);
		EIMSK|= (1<<INT0);
		/***********************************/
	}
	
	char rotation(void ){			// Deteccion de sentido de giro del encoder
		
		char comp1, comp2;
		
		comp2 = (PINC&(1<<CLK))>>CLK;
		comp1 = (PIND&(1<<DT))>>DT;
		
		if(comp1==comp2){return '+';}
		else{return '-';}
	}
